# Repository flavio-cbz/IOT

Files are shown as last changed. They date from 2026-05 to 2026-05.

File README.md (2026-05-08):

<div align="center">

# 🌿 Station IOT — La station connectée qui veille sur vos plantes

**Parce qu'une plante ne peut pas vous dire qu'elle souffre.**

> 🎓 Projet étudiant · ADI 2 · Groupe 4 · 2026





</div>

---

## 😔 Le constat

**En France, plus de 60% des plantes d'intérieur meurent faute d'entretien inadapté.**

Trop d'eau. Pas assez de lumière. Une chaleur excessive. Des erreurs souvent invisibles, et toujours découvertes trop tard.

Pourtant, nous aimons nos plantes. Nous les achetons, nous les décorons, nous les offrons. Mais sans les bons outils, nous sommes aveugles face à leurs besoins.

---

## ❓ La problématique

> *Comment savoir, en temps réel et sans être botaniste, si ma plante va bien ?*

Les solutions existantes sur le marché sont soit **trop chères** pour un usage domestique courant, soit **fermées** dans des écosystèmes propriétaires qui vous enfoncent dans des abonnements et des applications qui disparaissent du jour au lendemain.

Il manquait une solution **libre, transparente, auto-hébergée** — et surtout, **vraiment utile**.

---

## 💡 Notre solution : Station IOT

Notre **station de monitoring open-source** est conçue pour vous donner une vision claire et instantanée de l'état de vos plantes — construite de A à Z dans le cadre de notre projet étudiant ADI 2.

> 🌱 *Elle observe. Elle analyse. Elle vous alerte. Et elle le fait avec une interface qui donne le sourire.*

### Ce que la station surveille pour vous

| Mesure | Capteur | Utilité concrète |
|---|---|---|
| 💧 Humidité du sol | SEN0193 | Savoir quand arroser |
| 🌡️ Température ambiante | BMP280 | Détecter les coups de chaud ou de froid |
| 📊 Pression atmosphérique | BMP280 | Contexte climatique local |
| ☀️ Luminosité | BH1750 | Optimiser le placement de la plante |
| 🏔️ Altitude | BMP280 | Calibrage automatique |

### Ce que vous voyez

- **Un écran OLED embarqué** avec des animations : votre plante sourit quand elle est heureuse, elle vous supplie quand elle a soif.
- **Un dashboard web moderne**, accessible depuis n'importe quel appareil (mobile, tablette, PC), avec mode sombre et historique des données.



- **Des alertes en temps réel** — sans rafraîchissement manuel.

---

## ✨ Pourquoi PlantWatch plutôt qu'une autre solution ?

| | Solutions concurrentes | **PlantWatch** |
|---|---|---|
| 💰 Prix | 30 €–150 € + abonnement | Open-source & auto-hébergé |
| 🔒 Vie privée | Données envoyées dans le cloud | 100% chez vous |
| 🔧 Personnalisable | Non | Totalement |
| 📡 Connexion sécurisée | Variable | HTTPS + WSS (port 443) |
| 📱 Dashboard | App propriétaire | Interface web universelle |
| ♻️ Pérennité | Dépend de l'éditeur | Vous en êtes propriétaire |

---

## 🚀 Comment ça fonctionne ?

```
  [Plante] 🌿
      │
  [Station ESP32-S3]  ← Mesure en continu l'environnement
      │
      │ (Connexion chiffrée — WSS port 443)
      ▼
  [Nginx Reverse Proxy]
      │
      ├──▶  Dashboard Web  (HTTPS)
      └──▶  Broker MQTT    (WSS → /mqtt)
                │
                ▼
         [Backend Django + MongoDB]
              Stockage, analyse & diffusion temps réel
```

Tout tourne en **Docker** sur votre propre serveur ou NAS. Une seule commande suffit pour tout démarrer.

---

## ⚡ Mise en route en 3 étapes

### 1. Déployez le serveur

```bash
git clone https://github.com/votre-repo/station-iot.git
cd station-iot
docker compose up -d --build
```

> Le dashboard est immédiatement disponible sur `http://localhost:8095/`

### 2. Configurez votre accès sécurisé (optionnel mais recommandé)

Via **Nginx Proxy Manager**, créez un Proxy Host vers votre instance :

| Paramètre | Valeur |
|---|---|
| Domaine | `iot.votredomaine.com` |
| Destination | `http://<IP_SERVEUR>:8095` |
| SSL | ✅ Let's Encrypt |
| Custom Location `/mqtt` | Port `9002` — **WebSocket activé** |

### 3. Flashez votre station ESP32

```bash
cd firmware
pio run -t upload     # Compile et installe le firmware
pio device monitor    # Visualise les logs en direct
```

Au premier démarrage, la station crée un point d'accès Wi-Fi **"Station-Plante"**. Connectez-vous y depuis votre téléphone pour configurer votre réseau en 30 secondes.

---

## 🛠️ Stack technique

| Composant | Technologie |
|---|---|
| Microcontrôleur | ESP32-S3-OTG (Arduino / PlatformIO) |
| Affichage embarqué | OLED SSD1306 128×64 (I2C) |
| Communication | MQTT over WebSocket Secure (WSS) |
| Backend | Django + Django Channels (ASGI) |
| Base de données | MongoDB |
| Déploiement | Docker Compose |
| Proxy | Nginx Proxy Manager |

---

## 🩺 Diagnostic rapide

| Symptôme | Cause probable | Solution |
|---|---|---|
| ⚠️ `MQTT Disconnected` | WebSocket non activé dans Nginx | Activer "Websockets Support" pour `/mqtt` dans NPM |
| 🖤 Écran OLED éteint | Mauvais câblage I2C | Vérifier SDA=GPIO9, SCL=GPIO8 |
| 📉 Valeurs sol incohérentes | Calibration à ajuster | Modifier `SOIL_DRY` et `SOIL_WET` dans `main.cpp` |

---

## 📬 Contribuer

Ce projet est **ouvert à la communauté**. Qu'il s'agisse de corriger un bug, d'ajouter un nouveau capteur ou de proposer une amélioration d'interface — toutes les contributions sont les bienvenues.

> Ensemble, rendons les plantes immortelles. 🌍

---

<div align="center">

*Projet réalisé dans le cadre de l'ADI 2 · Groupe 4 · 2026*
*Construit avec ❤️, du café ☕ et beaucoup trop d'humidité de sol.*

</div>

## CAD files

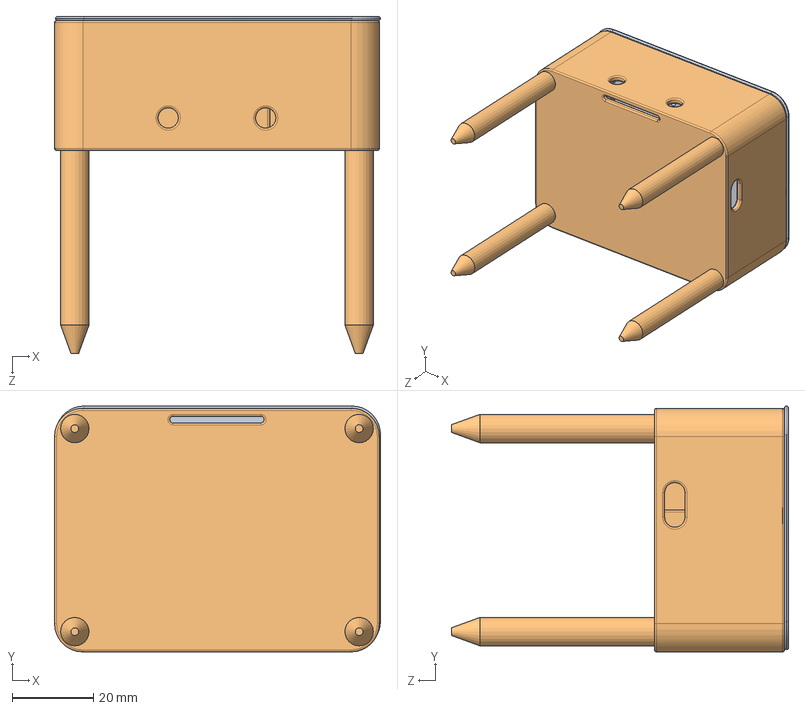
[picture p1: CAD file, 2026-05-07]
3d/assemblage boitier.SLDASM
80.3 x 60.5 x 83.0 mm
boitier
couvercleIOT

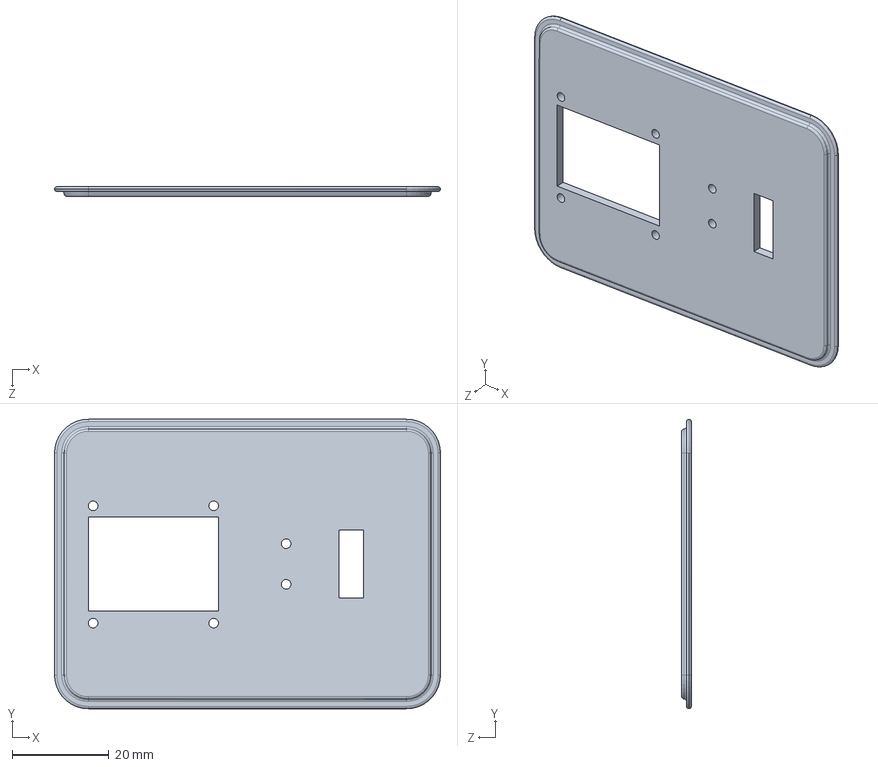
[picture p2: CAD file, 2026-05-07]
3d/couvercleIOT.SLDPRT
80.0 x 60.0 x 2.00 mm

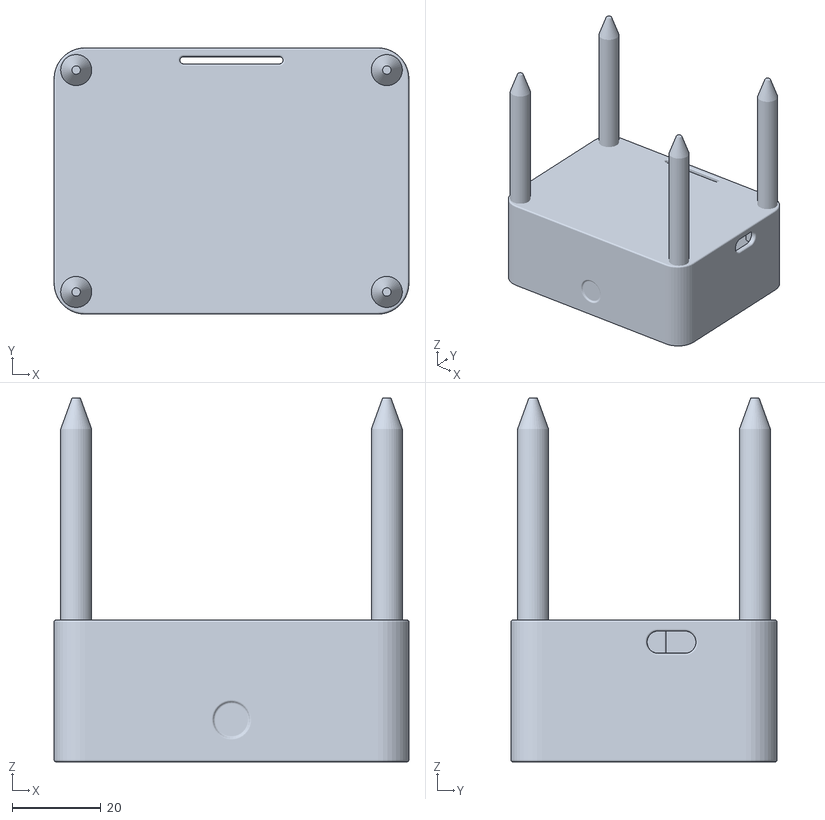
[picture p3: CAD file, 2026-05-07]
3d/boitierIOT.STL
80.0 x 60.0 x 82.0

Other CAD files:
3d/boitier.SLDPRT
3d/couvercleIOT.STL

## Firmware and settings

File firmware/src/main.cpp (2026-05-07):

#include <Adafruit_BMP280.h>
#include <Adafruit_GFX.h>
#include <Adafruit_NeoPixel.h>
#include <Adafruit_SSD1306.h>
#include <Arduino.h>
#include <ArduinoJson.h>
#include <BH1750.h>
#include <esp_crt_bundle.h>
#include <esp_wifi.h>
#include <WiFiManager.h>
#include <Wire.h>
#include <Preferences.h>
#include "mqtt_client.h"

// ============================================
// Configuration Hardware
// ============================================
#define PIN_SOIL 4
#define PIN_BUTTON 0 
#define PIN_TOUCH 13 
#define PIN_BUZZER 17
#define PIN_NEOPIXEL 48
#define NUM_PIXELS 1
#define FACTORY_RESET_HOLD_MS 5000
#define CONFIG_PORTAL_TIMEOUT_SEC 300
#define CONFIG_AP_SSID "Station-Plante"
#define MQTT_RECONNECT_INTERVAL_MS 15000
#define MQTT_PUBLISH_INTERVAL_MS 3000

#define I2C_SDA 9
#define I2C_SCL 8

#define SCREEN_WIDTH 128
#define SCREEN_HEIGHT 64
#define OLED_ADDR 0x3C

// Seuils pour le score de bonheur
#define SOIL_DRY 3000
#define SOIL_WET 1500

#ifndef STATION_ID
#define STATION_ID "adi_4"
#endif

// ============================================
// Variables Globales
// ============================================
Adafruit_SSD1306 display(SCREEN_WIDTH, SCREEN_HEIGHT, &Wire, -1);
Adafruit_BMP280 bmp;
BH1750 lightMeter;
Adafruit_NeoPixel pixel(NUM_PIXELS, PIN_NEOPIXEL, NEO_GRB + NEO_KHZ800);
Preferences prefs;

// Valeurs capteurs
float temperature = 0;
float pressure = 0;
float altitude = 0;
float soilHumidity = 0;
float lightLevel = 0;
int soilADC = 0;

// Variables de logique d'état
int currentScreen = 0;
const int NUM_NORMAL_SCREENS = 3; // 0:Scene, 1:Needs, 2:Journal
const int NUM_DEBUG_SCREENS = 4;  // 0:Capteurs, 1:Réseau, 2:Système, 3:Reset

bool debugMode = false;
int debugScreen = 0;
unsigned long touchPressStart = 0;
bool lastTouchStateIsPressed = false;
bool touchLongPressHandled = false; // Evite le skip d'écran au relâchement après long press
unsigned long lastTouchOverlayRefresh = 0; // Timer pour rafraîchir l'overlay
#define TOUCH_LONG_HOLD_MS 5000
#define TOUCH_OVERLAY_WARN_MS 2000 // Délai avant affichage avertissement debug

// MQTT Secure (WSS)
const char *MQTT_URI = "wss://iot.youcloud.ovh/mqtt";
const char *MQTT_TOPIC = "station/plantes/data";
const char *MQTT_CA_CERT = R"PEM(-----BEGIN CERTIFICATE-----
MIIFazCCA1OgAwIBAgIRAIIQz7DSQONZRGPgu2OCiwAwDQYJKoZIhvcNAQELBQAw
TzELMAkGA1UEBhMCVVMxKTAnBgNVBAoTIEludGVybmV0IFNlY3VyaXR5IFJlc2Vh
cmNoIEdyb3VwMRUwEwYDVQQDEwxJU1JHIFJvb3QgWDEwHhcNMTUwNjA0MTEwNDM4
WhcNMzUwNjA0MTEwNDM4WjBPMQswCQYDVQQGEwJVUzEpMCcGA1UEChMgSW50ZXJu
ZXQgU2VjdXJpdHkgUmVzZWFyY2ggR3JvdXAxFTATBgNVBAMTDElTUkcgUm9vdCBY
MTCCAiIwDQYJKoZIhvcNAQEBBQADggIPADCCAgoCggIBAK3oJHP0FDfzm54rVygc
h77ct984kIxuPOZXoHj3dcKi/vVqbvYATyjb3miGbESTtrFj/RQSa78f0uoxmyF+
0TM8ukj13Xnfs7j/EvEhmkvBioZxaUpmZmyPfjxwv60pIgbz5MDmgK7iS4+3mX6U
A5/TR5d8mUgjU+g4rk8Kb4Mu0UlXjIB0ttov0DiNewNwIRt18jA8+o+u3dpjq+sW
T8KOEUt+zwvo/7V3LvSye0rgTBIlDHCNAymg4VMk7BPZ7hm/ELNKjD+Jo2FR3qyH
B5T0Y3HsLuJvW5iB4YlcNHlsdu87kGJ55tukmi8mxdAQ4Q7e2RCOFvu396j3x+UC
B5iPNgiV5+I3lg02dZ77DnKxHZu8A/lJBdiB3QW0KtZB6awBdpUKD9jf1b0SHzUv
KBds0pjBqAlkd25HN7rOrFleaJ1/ctaJxQZBKT5ZPt0m9STJEadao0xAH0ahmbWn
OlFuhjuefXKnEgV4We0+UXgVCwOPjdAvBbI+e0ocS3MFEvzG6uBQE3xDk3SzynTn
jh8BCNAw1FtxNrQHusEwMFxIt4I7mKZ9YIqioymCzLq9gwQbooMDQaHWBfEbwrbw
qHyGO0aoSCqI3Haadr8faqU9GY/rOPNk3sgrDQoo//fb4hVC1CLQJ13hef4Y53CI
rU7m2Ys6xt0nUW7/vGT1M0NPAgMBAAGjQjBAMA4GA1UdDwEB/wQEAwIBBjAPBgNV
HRMBAf8EBTADAQH/MB0GA1UdDgQWBBR5tFnme7bl5AFzgAiIyBpY9umbbjANBgkq
hkiG9w0BAQsFAAOCAgEAVR9YqbyyqFDQDLHYGmkgJykIrGF1XIpu+ILlaS/V9lZL
ubhzEFnTIZd+50xx+7LSYK05qAvqFyFWhfFQDlnrzuBZ6brJFe+GnY+EgPbk6ZGQ
3BebYhtF8GaV0nxvwuo77x/Py9auJ/GpsMiu/X1+mvoiBOv/2X/qkSsisRcOj/KK
NFtY2PwByVS5uCbMiogziUwthDyC3+6WVwW6LLv3xLfHTjuCvjHIInNzktHCgKQ5
ORAzI4JMPJ+GslWYHb4phowim57iaztXOoJwTdwJx4nLCgdNbOhdjsnvzqvHu7Ur
TkXWStAmzOVyyghqpZXjFaH3pO3JLF+l+/+sKAIuvtd7u+Nxe5AW0wdeRlN8NwdC
jNPElpzVmbUq4JUagEiuTDkHzsxHpFKVK7q4+63SM1N95R1NbdWhscdCb+ZAJzVc
oyi3B43njTOQ5yOf+1CceWxG1bQVs5ZufpsMljq4Ui0/1lvh+wjChP4kqKOJ2qxq
4RgqsahDYVvTH9w7jXbyLeiNdd8XM2w9U/t7y0Ff/9yi0GE44Za4rF2LN9d11TPA
mRGunUHBcnWEvgJBQl9nJEiU0Zsnvgc/ubhPgXRR4Xq37Z0j4r7g1SgEEzwxA57d
emyPxgcYxn/eR44/KJ4EBs+lVDR3veyJm+kXQ99b21/+jh5Xos1AnX5iItreGCc=
-----END CERTIFICATE-----)PEM";

esp_mqtt_client_handle_t mqtt_client = NULL;
bool mqtt_connected = false;
char mqtt_status_text[24] = "OFFLINE";
unsigned long lastMqttReconnectAttempt = 0;
unsigned long lastMqttTime = 0;

// Variables pour le score et streak
float smoothedScore = 3.0; // Score de 0 à 5
unsigned long lastStateChangeMs = 0;
unsigned long streakStartSec = 0; 
int currentProblemCode = 0; // 0=OK, 1=Soif, 2=Noyée, 3=Sombre, 4=Froid, 5=Chaud

// Historique NVS
#define HIST_SIZE 20
uint8_t scores_history[HIST_SIZE] = {0};
uint8_t histIndex = 0;

// Timers
unsigned long lastReadTime = 0;
unsigned long lastButtonTime = 0;
unsigned long buttonPressStart = 0;
unsigned long lastNvsSaveTime = 0;
unsigned long lastSceneRefreshTime = 0;
unsigned long uptimeSec = 0;
unsigned long lastUptimeUpdateMs = 0;
int lastButtonState = HIGH;
int lastTouchState = LOW;
// factoryResetArmed supprimé — reset géré uniquement via mode debug tactile

// ============================================
// Prototypes
// ============================================
void readSensors();
void updateHappinessScore();
void saveHistoryNVS();
void loadHistoryNVS();
void addHistoryPoint(int stars);
void refreshDisplay();
void ensureMQTTConnection();
void initMQTT();
void setMqttStatus(const char *status);
void formatDuration(unsigned long seconds, char* buffer);
void getProblemText(int code, char* buffer, unsigned long durationSec);
void refreshDisplay(unsigned long touchElapsedMs);
void drawNeedsScreen();
void drawResetProgressBar(unsigned long elapsedMs);
void drawWaterDrop(int x, int y);
void drawSunIcon(int x, int y);
void drawThermometerIcon(int x, int y);
void drawDebugSensorsScreen();
void drawDebugNetworkScreen();
void drawDebugSystemScreen();
void drawDebugResetScreen();
void drawLongPressOverlay(unsigned long elapsedMs);

// ============================================
// MQTT Events
// ============================================
void mqtt_event_handler(void *handler_args, esp_event_base_t base, int32_t event_id, void *event_data) {
    esp_mqtt_event_handle_t event = (esp_mqtt_event_handle_t)event_data;
    switch ((esp_mqtt_event_id_t)event_id) {
    case MQTT_EVENT_CONNECTED:
        mqtt_connected = true;
        setMqttStatus("OK");
        break;
    case MQTT_EVENT_DISCONNECTED:
        mqtt_connected = false;
        setMqttStatus("DISC");
        break;
    case MQTT_EVENT_ERROR:
        mqtt_connected = false;
        setMqttStatus("ERROR");
        break;
    default:
        break;
    }
}

void setMqttStatus(const char *status) {
  if (status) snprintf(mqtt_status_text, sizeof(mqtt_status_text), "%s", status);
}

void initMQTT() {
  esp_mqtt_client_config_t mqtt_cfg = {};
  mqtt_cfg.uri = MQTT_URI;
  mqtt_cfg.cert_pem = MQTT_CA_CERT;
  mqtt_cfg.client_id = STATION_ID;
  mqtt_cfg.reconnect_timeout_ms = MQTT_RECONNECT_INTERVAL_MS;
  mqtt_client = esp_mqtt_client_init(&mqtt_cfg);
  esp_mqtt_client_register_event(mqtt_client, (esp_mqtt_event_id_t)ESP_EVENT_ANY_ID, mqtt_event_handler, NULL);
  setMqttStatus("CONN...");
  esp_mqtt_client_start(mqtt_client);
}

void ensureMQTTConnection() {
  if (WiFi.status() != WL_CONNECTED) return;
  if (mqtt_connected || mqtt_client == NULL) return;
  if (millis() - lastMqttReconnectAttempt < MQTT_RECONNECT_INTERVAL_MS) return;
  lastMqttReconnectAttempt = millis();
  setMqttStatus("RETRY");
  esp_mqtt_client_reconnect(mqtt_client);
}

// ============================================
// Core Logic : Tamagotchi Score & NVS
// ============================================
void loadHistoryNVS() {
  prefs.begin("plant", true); // read-only
  size_t len = prefs.getBytes("scores", scores_history, HIST_SIZE);
  if (len == 0) {
    for(int i=0; i<HIST_SIZE; i++) scores_history[i] = 3; // Default
  }
  histIndex = prefs.getUChar("idx", 0);
  streakStartSec = prefs.getUInt("streakT", 0); // en temps absolu ? Non, l'ESP n'a pas de RTC par défaut
  // Si pas de RTC, on va utiliser l'uptime et stocker un diff lors du boot.
  // Pour la simplicité ici, on va recréer le streak à 0 au boot, car sans WiFi+NTP on ne connaît pas l'heure réelle.
  // Pour faire mieux, on pourrait stocker la durée totale, mais restons simple :
  uptimeSec = prefs.getUInt("upSec", 0);
  streakStartSec = prefs.getUInt("streakStart", uptimeSec); 
  prefs.end();
}

void saveHistoryNVS() {
  prefs.begin("plant", false); // rw
  prefs.putBytes("scores", scores_history, HIST_SIZE);
  prefs.putUChar("idx", histIndex);
  prefs.putUInt("upSec", uptimeSec);
  prefs.putUInt("streakStart", streakStartSec);
  prefs.end();
}

void addHistoryPoint(int stars) {
  scores_history[histIndex] = (uint8_t)stars;
  histIndex = (histIndex + 1) % HIST_SIZE;
  saveHistoryNVS();
}

void updateHappinessScore() {
  // Score Eau (0.0 à 1.0)
  float sEau = 0;
  int probEau = 0;
  if (soilHumidity >= 40 && soilHumidity <= 70) { sEau = 1.0; probEau = 0; }
  else if (soilHumidity >= 30 && soilHumidity <= 85) { sEau = 0.5; probEau = (soilHumidity < 40) ? 1 : 2; }
  else { sEau = 0.0; probEau = (soilHumidity < 30) ? 1 : 2; }

  // Score Lumière
  float sLum = 0;
  int probLum = 0;
  if (lightLevel >= 200) { sLum = 1.0; probLum = 0; }
  else if (lightLevel >= 50) { sLum = 0.5; probLum = 3; }
  else { sLum = 0.0; probLum = 3; }

  // Score Température
  float sTemp = 0;
  int probTemp = 0;
  if (temperature >= 18 && temperature <= 26) { sTemp = 1.0; probTemp = 0; }
  else if ((temperature >= 15 && temperature < 18) || (temperature > 26 && temperature <= 30)) { sTemp = 0.5; probTemp = (temperature < 18) ? 4 : 5; }
  else { sTemp = 0.0; probTemp = (temperature < 15) ? 4 : 5; }

  float rawScore = ((sEau + sLum + sTemp) / 3.0) * 5.0; // Sur 5
  
  // Déterminer le problème prioritaire (0 = OK)
  int newProblem = 0;
  if (probEau == 1) newProblem = 1; // Soif prime
  else if (probTemp == 5) newProblem = 5; // Chaud
  else if (probTemp == 4) newProblem = 4; // Froid
  else if (probEau == 2) newProblem = 2; // Noyée
  else if (probLum == 3) newProblem = 3; // Sombre

  // Lissage du score
  smoothedScore = (0.3 * rawScore) + (0.7 * smoothedScore);
  
  // Gestion du Streak
  if (newProblem != currentProblemCode) {
    currentProblemCode = newProblem;
    streakStartSec = uptimeSec;
    saveHistoryNVS();
  }
}

void formatDuration(unsigned long seconds, char* buffer) {
  if (seconds < 60) snprintf(buffer, 16, "%lu sec", seconds);
  else if (seconds < 3600) snprintf(buffer, 16, "%lu min", seconds / 60);
  else if (seconds < 86400) snprintf(buffer, 16, "%lu h", seconds / 3600);
  else snprintf(buffer, 16, "%lu j", seconds / 86400);
}

void getProblemText(int code, char* buffer, unsigned long durationSec) {
  char timeStr[16];
  formatDuration(durationSec, timeStr);
  switch (code) {
    case 0: snprintf(buffer, 32, "Je suis bien depuis %s", timeStr); break;
    case 1: snprintf(buffer, 32, "J'ai soif depuis %s", timeStr); break;
    case 2: snprintf(buffer, 32, "Je me noie depuis %s", timeStr); break;
    case 3: snprintf(buffer, 32, "Je suis a l'ombre depuis %s", timeStr); break;
    case 4: snprintf(buffer, 32, "J'ai froid depuis %s", timeStr); break;
    case 5: snprintf(buffer, 32, "J'ai chaud depuis %s", timeStr); break;
    default: snprintf(buffer, 32, "Etat inconnu"); break;
  }
}

// ============================================
// drawStar — 7x5px, lisible sur SSD1306
// ============================================
void drawStar(int x, int y, bool filled) {
  // Forme en losange-étoile 7px de large
  display.drawPixel(x+3, y,   SSD1306_WHITE);
  display.drawPixel(x+2, y+1, SSD1306_WHITE);
  display.drawPixel(x+3, y+1, SSD1306_WHITE);
  display.drawPixel(x+4, y+1, SSD1306_WHITE);
  if (filled) {
    display.drawLine(x,   y+2, x+6, y+2, SSD1306_WHITE);
    display.drawLine(x+1, y+3, x+5, y+3, SSD1306_WHITE);
  } else {
    display.drawPixel(x,   y+2, SSD1306_WHITE);
    display.drawPixel(x+6, y+2, SSD1306_WHITE);
    display.drawPixel(x+1, y+3, SSD1306_WHITE);
    display.drawPixel(x+5, y+3, SSD1306_WHITE);
  }
  display.drawPixel(x+2, y+4, SSD1306_WHITE);
  display.drawPixel(x+4, y+4, SSD1306_WHITE);
}

// ============================================
// drawSky — confiné à x < 42 pour ne pas
// déborder sur la zone plante (cx=62)
// ============================================
void drawSky(int lux) {
  if (lux > 500) {
    // Soleil
    int anim = (millis() / 500) % 2;
    display.drawCircle(16, 10, 5, SSD1306_WHITE);
    if (anim) {
      display.drawLine(16, 2,  16, 0,  SSD1306_WHITE);
      display.drawLine(16, 18, 16, 20, SSD1306_WHITE);
      display.drawLine(8,  10, 6,  10, SSD1306_WHITE);
      display.drawLine(24, 10, 26, 10, SSD1306_WHITE);
    } else {
      display.drawLine(10, 4,  8,  2,  SSD1306_WHITE);
      display.drawLine(22, 16, 24, 18, SSD1306_WHITE);
      display.drawLine(10, 16, 8,  18, SSD1306_WHITE);
      display.drawLine(22, 4,  24, 2,  SSD1306_WHITE);
    }
  } else if (lux > 50) {
    // Nuages (max x=40)
    display.fillCircle(18, 11, 4, SSD1306_WHITE);
    display.fillCircle(24, 9,  6, SSD1306_WHITE);
    display.fillCircle(30, 11, 4, SSD1306_WHITE);
    display.fillRect(18, 11, 12, 5, SSD1306_WHITE);
  } else {
    // Lune croissant
    display.fillCircle(16, 11, 5, SSD1306_WHITE);
    display.fillCircle(19, 8,  5, SSD1306_BLACK);
  }
}

// ============================================
// drawGiantPlant — cx=62, ySol=50
// Fix: fRad cappé pour éviter dessin hors écran
// ============================================
void drawGiantPlant(int cx, int baseY, int stars, int problemCode) {
  // stemTop ajusté : jamais < 10 pour garder fleur visible
  int stemTop = 10;
  if (problemCode == 1) stemTop = 20; // Soif: plante affaissée
  if (problemCode == 4) stemTop = 23; // Froid: plante ramassée

  // Pot
  int potW = 28, potH = 10;
  int potX  = cx - potW/2;
  int potTop = baseY - potH;
  display.fillRect(potX, potTop, potW, potH, SSD1306_WHITE);
  display.fillRect(potX+2, potTop+2, potW-4, potH-4, SSD1306_BLACK);
  display.fillRect(potX-3, potTop-3, potW+6, 4, SSD1306_WHITE);
  display.fillRect(potX-1, potTop-2, potW+2, 2, SSD1306_BLACK);

  int stemBase = potTop - 3;

  // Tige (inclinée si soif)
  int cxStem = cx;
  if (problemCode == 1) {
    display.drawLine(cx,   stemBase, cx-7, stemTop, SSD1306_WHITE);
    display.drawLine(cx+1, stemBase, cx-6, stemTop, SSD1306_WHITE);
    display.drawLine(cx-1, stemBase, cx-8, stemTop, SSD1306_WHITE);
    cxStem = cx - 7;
  } else {
    display.drawLine(cx-1, stemBase, cx-1, stemTop, SSD1306_WHITE);
    display.drawLine(cx,   stemBase, cx,   stemTop, SSD1306_WHITE);
    display.drawLine(cx+1, stemBase, cx+1, stemTop, SSD1306_WHITE);
  }

  // Feuilles
  int leafY = stemBase - (stemBase - stemTop) / 3;
  if (stars >= 4) {
    display.fillCircle(cxStem-14, leafY-2, 7, SSD1306_WHITE);
    display.fillCircle(cxStem-9,  leafY+1, 5, SSD1306_WHITE);
    display.fillCircle(cxStem+14, leafY-4, 7, SSD1306_WHITE);
    display.fillCircle(cxStem+9,  leafY-1, 5, SSD1306_WHITE);
    // Tige redessinée par-dessus les feuilles
    display.drawLine(cx-1, stemBase, cx-1, stemTop, SSD1306_WHITE);
    display.drawLine(cx,   stemBase, cx,   stemTop, SSD1306_WHITE);
    display.drawLine(cx+1, stemBase, cx+1, stemTop, SSD1306_WHITE);
  } else if (problemCode == 1 || problemCode == 5) {
    display.fillCircle(cxStem-8, leafY+6, 4, SSD1306_WHITE);
    display.fillCircle(cxStem+8, leafY+5, 4, SSD1306_WHITE);
  } else {
    display.fillCircle(cxStem-11, leafY,   5, SSD1306_WHITE);
    display.fillCircle(cxStem+11, leafY-2, 5, SSD1306_WHITE);
  }

  // Fleur — fRad cappé pour rester dans l'écran
  int fRad = (stars >= 4) ? 9 : (stars >= 3 ? 6 : 4);
  fRad = min(fRad, stemTop - 2); // JAMAIS hors écran

  if (problemCode == 1 || stars < 2) {
    // Bouton fermé / fanée
    display.drawCircle(cxStem, stemTop, fRad, SSD1306_WHITE);
    display.drawPixel(cxStem-2, stemTop+fRad+2, SSD1306_WHITE);
    display.drawPixel(cxStem+2, stemTop+fRad+3, SSD1306_WHITE);
  } else {
    // Fleur épanouie 6 pétales
    int pr = fRad - 1;
    display.fillCircle(cxStem,        stemTop-fRad,    pr, SSD1306_WHITE);
    display.fillCircle(cxStem+fRad,   stemTop-fRad/2,  pr, SSD1306_WHITE);
    display.fillCircle(cxStem+fRad,   stemTop+fRad/2,  pr, SSD1306_WHITE);
    display.fillCircle(cxStem,        stemTop+fRad,    pr, SSD1306_WHITE);
    display.fillCircle(cxStem-fRad,   stemTop+fRad/2,  pr, SSD1306_WHITE);
    display.fillCircle(cxStem-fRad,   stemTop-fRad/2,  pr, SSD1306_WHITE);
    display.fillCircle(cxStem, stemTop, fRad,    SSD1306_BLACK);
    display.fillCircle(cxStem, stemTop, fRad/2+1, SSD1306_WHITE);
  }
}
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
void loop() {
  unsigned long now = millis();

  // Uptime update
  if (now - lastUptimeUpdateMs >= 1000) {
    uptimeSec += (now - lastUptimeUpdateMs) / 1000;
    lastUptimeUpdateMs = now;
  }

  // Navigation Bouton & Touch
  int btnState = digitalRead(PIN_BUTTON);
  int touchState = digitalRead(PIN_TOUCH);
  bool touchIsPressed = (touchState == HIGH);

  // Bouton Physique Logic
  if (btnState == LOW && lastButtonState == HIGH) {
    buttonPressStart = now;
  }
  if (btnState == HIGH && lastButtonState == LOW) {
    if (now - buttonPressStart < 1000) { // Court appui
      if (debugMode) {
        debugScreen = (debugScreen + 1) % NUM_DEBUG_SCREENS;
        if (debugScreen == 0) { debugMode = false; } // Sort après le tour complet
      } else {
        currentScreen = (currentScreen + 1) % NUM_NORMAL_SCREENS;
      }
      refreshDisplay();
    }
  }

  // Capteur Tactile Logic
  if (touchIsPressed && !lastTouchStateIsPressed) {
    // Front montant : début d'un appui
    touchPressStart = now;
    lastTouchStateIsPressed = true;
    touchLongPressHandled = false;
  } else if (!touchIsPressed && lastTouchStateIsPressed) {
    // Front descendant : relâchement
    unsigned long elapsed = now - touchPressStart;
    if (!touchLongPressHandled && elapsed < TOUCH_LONG_HOLD_MS) {
      // Court appui
      if (now - lastButtonTime > 250) {
        if (debugMode) {
          debugScreen = (debugScreen + 1) % NUM_DEBUG_SCREENS;
          if (debugScreen == 0) { debugMode = false; } // Sort du debug après avoir fait le tour
        } else {
          currentScreen = (currentScreen + 1) % NUM_NORMAL_SCREENS;
        }
        lastButtonTime = now;
        refreshDisplay();
      }
    }
    lastTouchStateIsPressed = false;
    touchLongPressHandled = false;
  }

  // Vérification de l'appui long tactile en continu
  if (touchIsPressed && lastTouchStateIsPressed && !touchLongPressHandled) {
    unsigned long elapsed = now - touchPressStart;
    if (elapsed >= TOUCH_LONG_HOLD_MS) {
      // Long press atteint
      touchLongPressHandled = true;
      if (!debugMode) {
        // Passage en mode debug
        debugMode = true;
        debugScreen = 0;
        refreshDisplay();
      } else if (debugScreen == NUM_DEBUG_SCREENS - 1) {
        // Reset d'usine depuis l'écran Reset
        display.clearDisplay();
        display.setCursor(10, 28);
        display.println(F("RESET WIFI..."));
        display.display();
        WiFiManager wm;
        wm.resetSettings();
        delay(1000);
        ESP.restart();
      }
    } else if (debugMode && debugScreen == NUM_DEBUG_SCREENS - 1 && elapsed >= TOUCH_OVERLAY_WARN_MS) {
      // Barre de progression pendant l'appui sur l'écran Reset
      drawResetProgressBar(elapsed);
    } else if (!debugMode && elapsed >= TOUCH_OVERLAY_WARN_MS) {
      // Overlay avertissement en mode normal — rafraîchir toutes les 200ms
      if (now - lastTouchOverlayRefresh > 200) {
        lastTouchOverlayRefresh = now;
        refreshDisplay(elapsed);
      }
    }
  }

  lastButtonState = btnState;
  lastTouchState = touchState;

  // Lecture Capteurs (2s)
  if (now - lastReadTime > 2000) {
    readSensors();
    updateHappinessScore();
    lastReadTime = now;
    
    // LED Statut
    if (currentProblemCode == 1) pixel.setPixelColor(0, pixel.Color(50, 20, 0)); // Orange/Soif
    else if (currentProblemCode == 4) pixel.setPixelColor(0, pixel.Color(0, 0, 50)); // Bleu/Froid
    else pixel.setPixelColor(0, pixel.Color(0, 20, 0)); // Vert/OK
    pixel.show();

    if (!debugMode && currentScreen == 0) refreshDisplay();
  }

  // Animation Scène fluide (si écran 0)
  if (!debugMode && currentScreen == 0 && (now - lastSceneRefreshTime > 250)) {
    lastSceneRefreshTime = now;
    refreshDisplay();
  }

  // Historique NVS sauvegarde score par intervalles de 12 mins (720s)
  if (uptimeSec - lastNvsSaveTime > 720) {
    addHistoryPoint(round(smoothedScore));
    lastNvsSaveTime = uptimeSec;
  }

  // MQTT (3s)
  if (now - lastMqttTime > MQTT_PUBLISH_INTERVAL_MS) {
    if (mqtt_connected) {
      StaticJsonDocument<256> doc;
      doc["station_id"] = STATION_ID;
      doc["temperature"] = temperature;
      doc["pressure"] = pressure;
      doc["soil_humidity"] = soilHumidity;
      doc["light_level"] = lightLevel;
      doc["happiness"] = smoothedScore;
      doc["problem_code"] = currentProblemCode;
      
      char buffer[256];
      serializeJson(doc, buffer);
      esp_mqtt_client_publish(mqtt_client, MQTT_TOPIC, buffer, 0, 1, 0);
    } else {
      ensureMQTTConnection();
    }
    lastMqttTime = now;
  }

  delay(10);
}
